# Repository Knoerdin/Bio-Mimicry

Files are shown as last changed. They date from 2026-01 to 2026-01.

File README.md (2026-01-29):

# Bio-Mimicry

## Code:
This project does not make use of any code, as the project is entirely analogue. However, there is a piece of simulation code for determining the deflection of different materials. Below is an explanation of how to use this code:
### Step 1:
To run the code, you'll need to install all dependencies. Do this by installing the requirements.txt file with this command:
```
pip install -r requirements.txt
```
### Step 2:
Now that you can run the code (assuming Python is installed...), go to the directory with the deflection.py in it and run the following command:
```
python3 deflection.py
```
This should start prompting values for these variables:
-   Material **name**
-   Beam **length** in meters
-   Beam **diameter** in centimeters
-   Beam **thickness** in millimeters
-   Material **modulus** of elasticity in pascals
-   Material **density** in kg/m³

After giving these variables a value, the program will ask you if you'd like to enter another entry. **Saying yes** will result in the same six questions and another entry in the data file. **Saying no** will plot all entries in the data file as a bar plot.\
When you are done with the simulation or need to exit, the data of the materials will be saved in deflection_results.txt for ease of use the next time the simulation is run.
## STL Files

This folder contains all 3D-printable parts used in the final prototype of the biomimetic bouldering hold gripper. The system consists of a pole-mounted tool head with a granular-jamming vacuum gripper, integrated drilling capability, onboard vacuum pump, and battery power supply.

### `accu_holder_los_helft.stl`
Single half of the slide-in battery holder that secures the battery pack and prevents connector movement during use.

### `conncection_drill_and_pole.stl`
Connector part that mechanically couples the drill and gripper head assembly to the aluminium pole.

### `filling_rig.stl`
Assembly aid used to hold the silicone membrane and clamping parts upright while filling the gripper with granular material.

### `handvat_half.stl`
One half of the handle shell that clamps around the pole and houses wiring, switches, and the drill trigger mechanism. To get the other half, just mirror this STL file before printing.

### `hinge_drill_connection.stl`
Tool-head-side hinge component that connects the gripper/drill assembly to the hinge mechanism.

### `hinge_pole_connection.stl`
Pole-side hinge component that mounts to the aluminium pole and the other hinge component

### `pump_holder+accu_helf_connected.stl`
Combined mount for the vacuum pump and battery interface that attaches to the pole and acts as a counterweight.

### `silicone_attachement_rings.stl`
Clamping rings used to secure the silicone membrane and create an airtight seal for the vacuum gripper.

### `silicone_cap_vacuum_attachment.stl`
Top cap of the gripper that connects the silicone membrane to the vacuum tubing. There is also a cutout for a ring filter.

### `silicone_mould_final_design.stl`
Mould used for casting the final silicone gripper membrane geometry.

## Miscellaneous:
Under the MISC folder, you'll find the poster used in the poster presentation given in Delft.
You'll also find the drawn electrical circuit connecting the drill and vacuum pump to the battery.

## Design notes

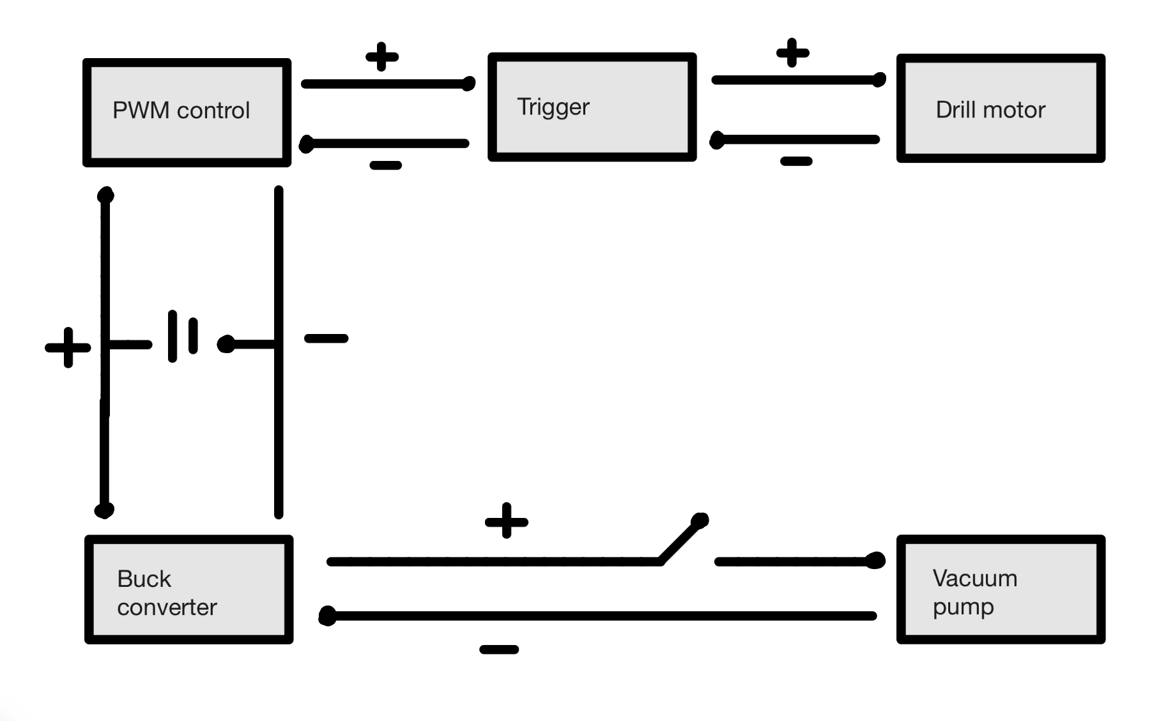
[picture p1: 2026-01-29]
MISC/electrical_circuit.jpg

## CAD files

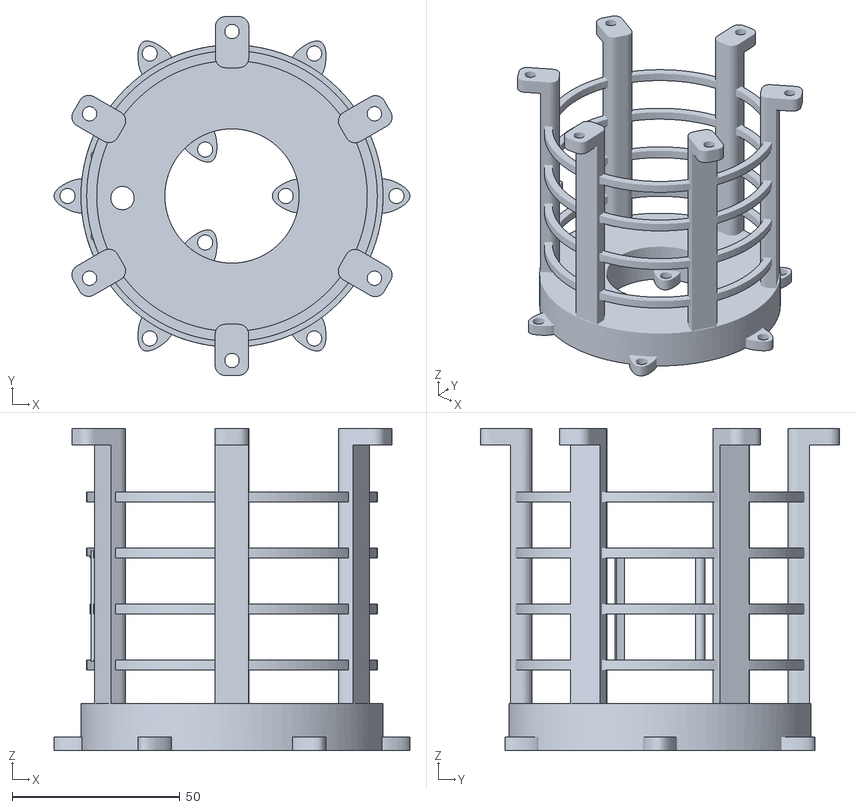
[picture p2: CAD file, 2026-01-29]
STL/silicone_cap_vacuum_attachment.stl
106.0 x 106.9 x 96.0

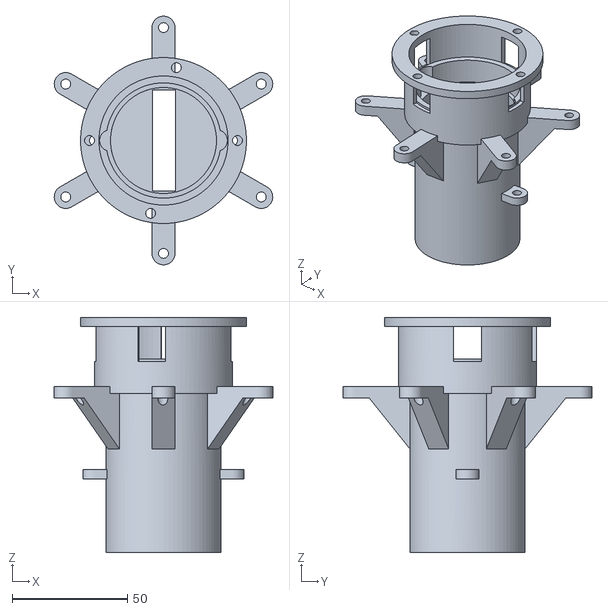
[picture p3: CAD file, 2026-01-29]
STL/conncection_drill_and_pole.stl
94.9 x 108.0 x 102.0

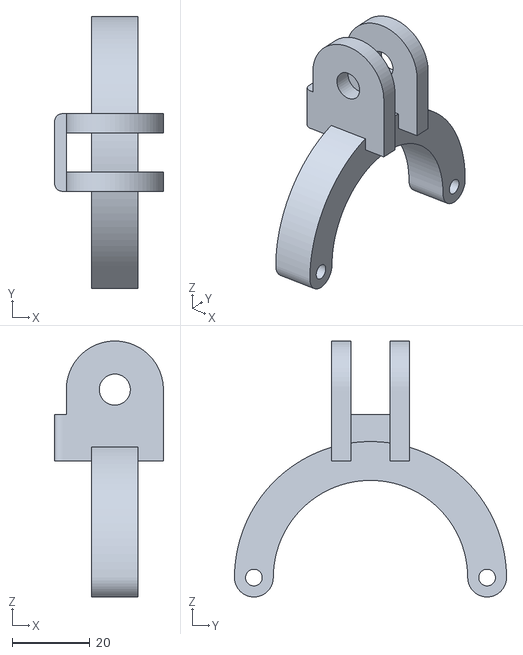
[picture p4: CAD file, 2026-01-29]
STL/hinge_drill_connection.stl
28.0 x 70.0 x 65.9

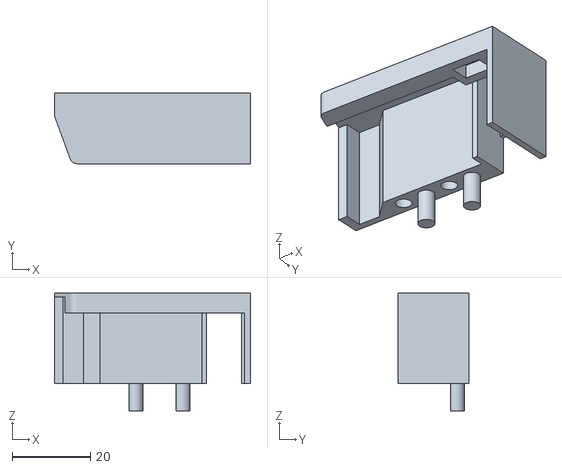
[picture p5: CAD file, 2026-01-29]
STL/accu_holder_los_helft.stl
50.0 x 18.0 x 30.0

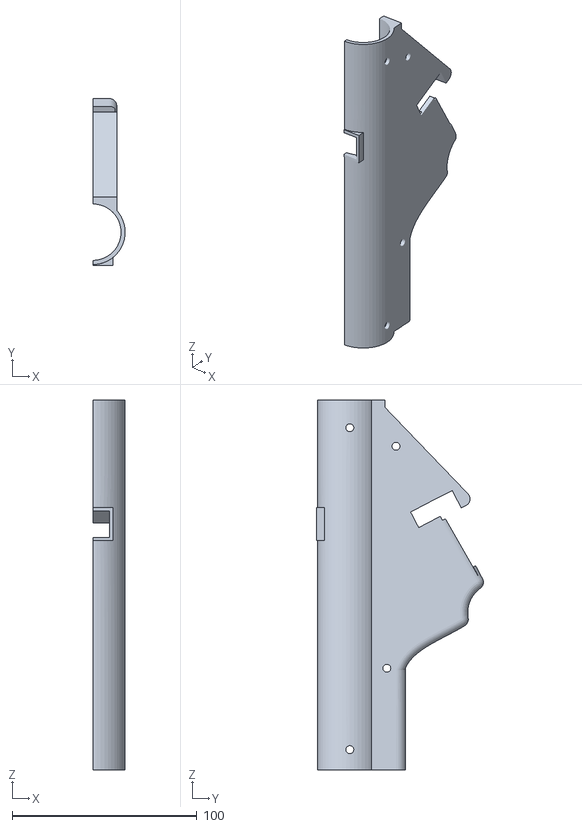
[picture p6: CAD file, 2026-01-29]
STL/handvat_half.stl
17.5 x 90.2 x 200.0

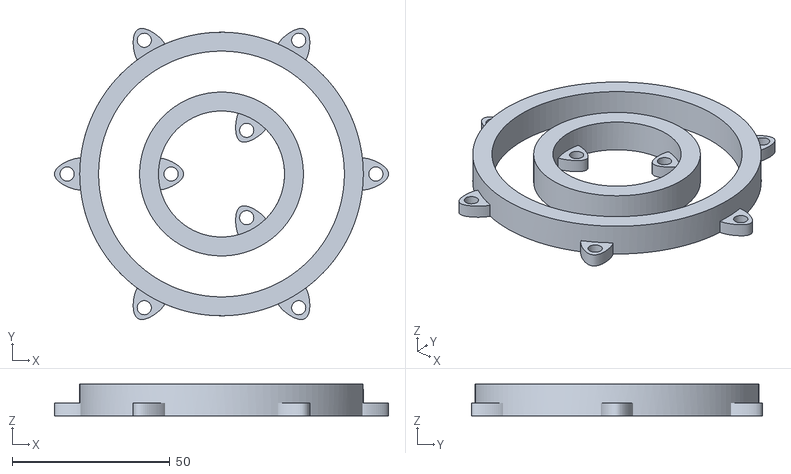
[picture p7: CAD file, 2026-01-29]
STL/silicone_attechement_rings.stl
106.0 x 92.4 x 10.0

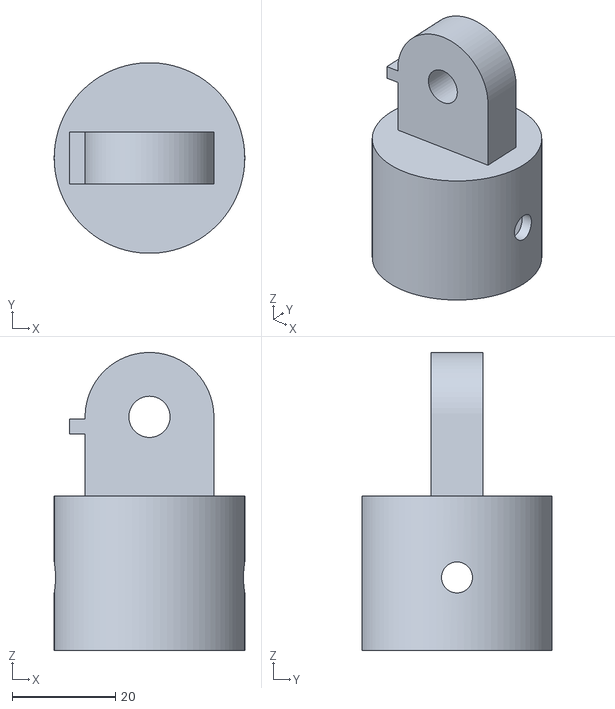
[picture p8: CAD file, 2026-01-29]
STL/hinge_pole_connection.stl
37.0 x 37.0 x 57.9

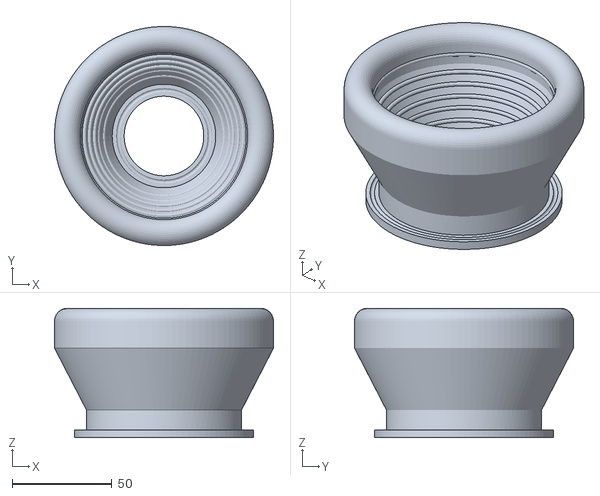
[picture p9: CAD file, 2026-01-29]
STL/silicone_mould_final_design.stl
110.0 x 110.0 x 65.0

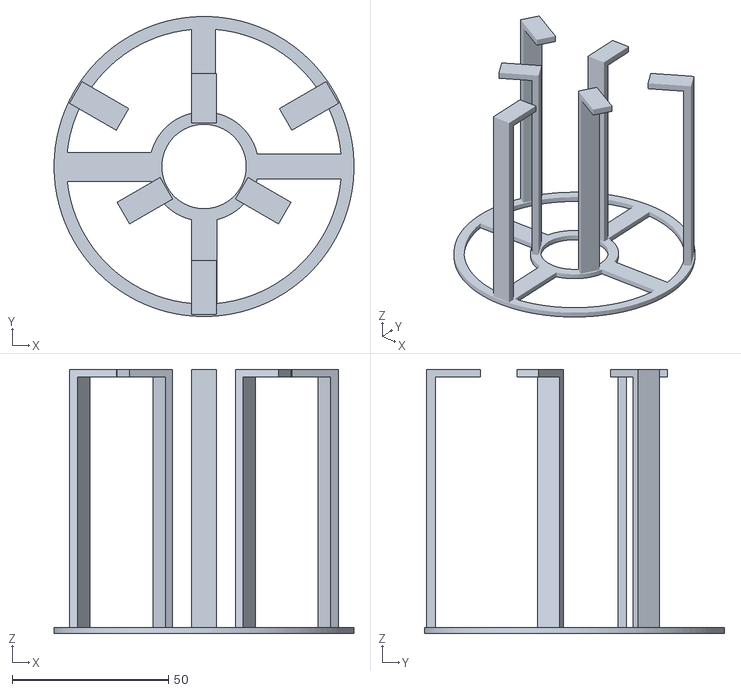
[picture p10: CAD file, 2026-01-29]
STL/filling_rig.stl
96.0 x 96.0 x 84.5

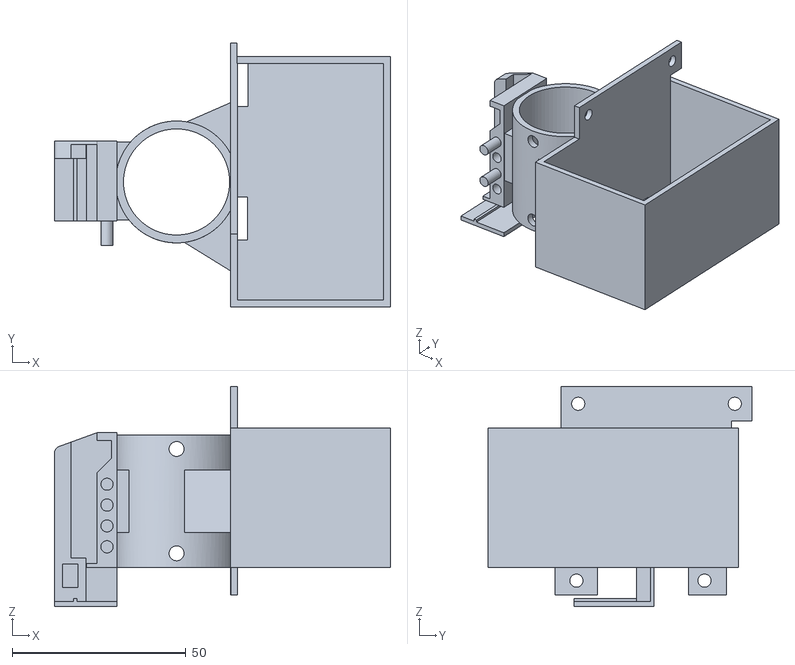
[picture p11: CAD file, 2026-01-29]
STL/pump_holder+accu_helf_connected.stl
96.6 x 76.0 x 63.3

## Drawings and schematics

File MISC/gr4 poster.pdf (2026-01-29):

1) Problem & Context | 2) First concepts

# Plan A

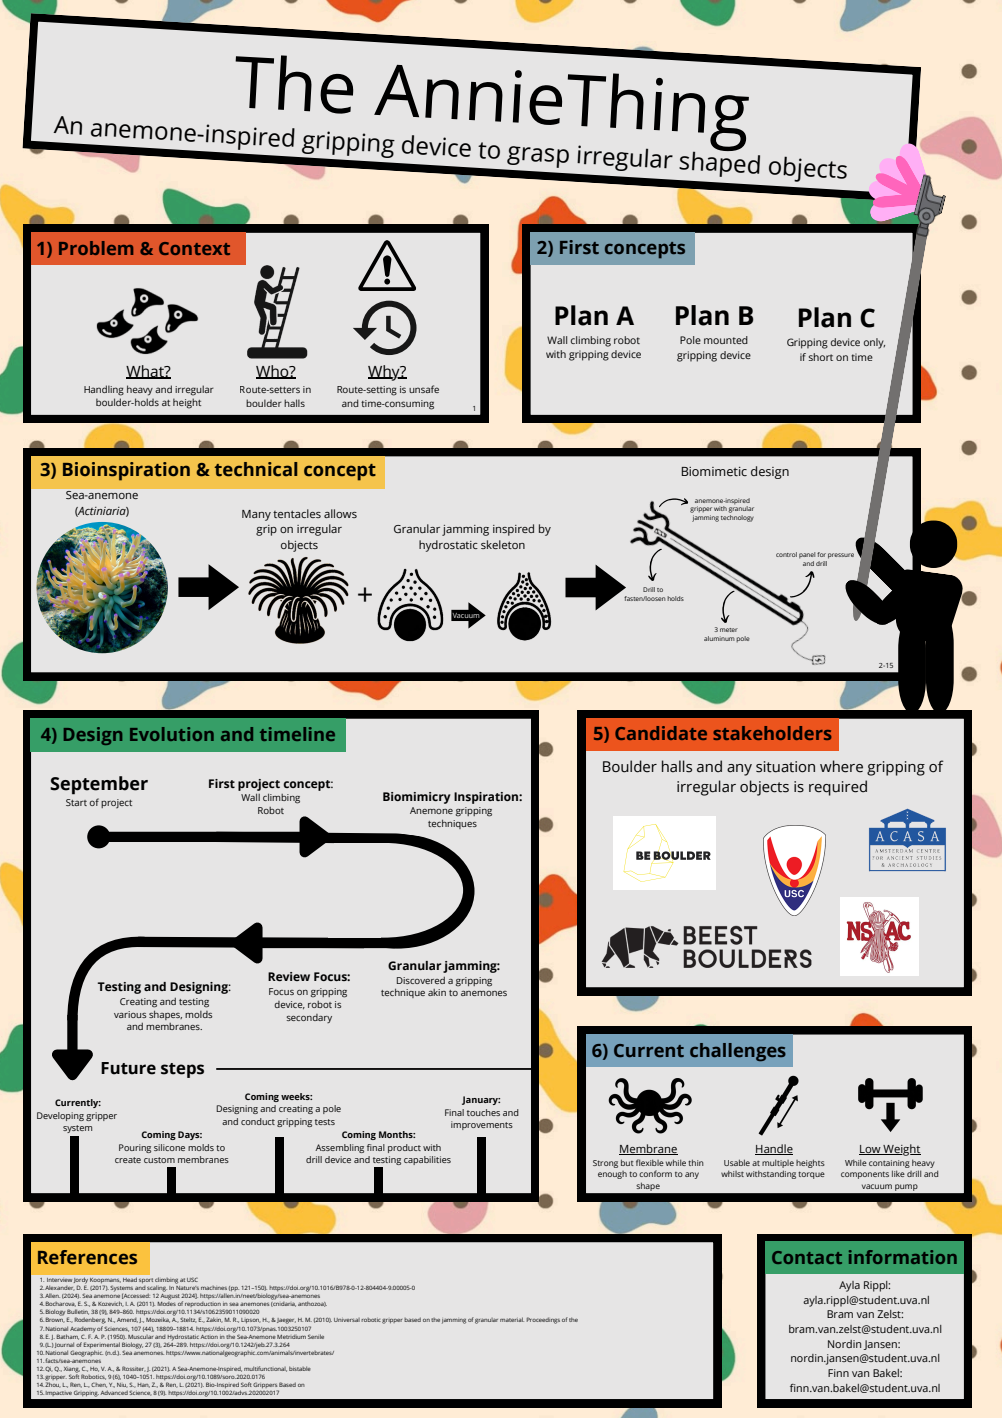
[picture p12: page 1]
Biomimetic design; and drill; 3 meter aluminum pole; Vacuum; The AnnieThing; References; Contact information; 6) Current challenges; 4) Design Evolution and timeline; 5) Candidate stakeholders; What?; Who?; Why?; Sea-anemone (Actiniaria); September; Biomimicry Inspiration: Anemone gripping techniques; Plan B; Pole mounted gripping device; Plan C; shape; Currently: Developing gripper system

An anemone-inspired gripping device to grasp irregular shaped objects

Wall climbing robot
with gripping device

Gripping device only,
if short on time

Handling heavy and irregular
boulder-holds at height

Route-setters in
boulder halls

Route-setting is unsafe
and time-consuming

3) Bioinspiration & technical concept

anemone-inspired
gripper with granular
jamming technology

Many tentacles allows
grip on irregular
objects

Granular jamming inspired by
hydrostatic skeleton

control panel for pressure

Drill to
fasten/loosen holds

Boulder halls and any situation where gripping of

First project concept:
Wall climbing
Robot

irregular objects is required

Start of project

Granular jamming:
Discovered a gripping
technique akin to anemones

Review Focus:
Focus on gripping
device, robot is
secondary

Testing and Designing:
Creating and testing
various shapes, molds
and membranes.
Future steps

Coming weeks:
Designing and creating a pole
and conduct gripping tests

January:
Final touches and
improvements

Coming Days:
Pouring silicone molds to
create custom membranes

Coming Months:
Assembling final product with
drill device and testing capabilities

Membrane
Strong but flexible while thin
enough to conform to any

Handle
Usable at multiple heights
whilst withstanding torque

Low Weight
While containing heavy
components like drill and
vacuum pump

1. Interview Jordy Koopmans, Head sport climbing at USC
2.Alexander, D. E. (2017). Systems and scaling. In Nature’s machines (pp. 121–150). https://doi.org/10.1016/B978-0-12-804404-9.00005-0
3.Allen. (2024). Sea anemone [Accessed: 12 August 2024]. https://allen.in/neet/biology/sea-anemones
4.Bocharova, E. S., & Kozevich, I. A. (2011). Modes of reproduction in sea anemones (cnidaria, anthozoa).
5.Biology Bulletin, 38 (9), 849–860. https://doi.org/10.1134/s1062359011090020
6.Brown, E., Rodenberg, N., Amend, J., Mozeika, A., Steltz, E., Zakin, M. R., Lipson, H., & Jaeger, H. M. (2010). Universal robotic gripper based on the jamming of granular material. Proceedings of the
7.National Academy of Sciences, 107 (44), 18809–18814. https://doi.org/10.1073/pnas.1003250107
8.E. J. Batham, C. F. A. P. (1950). Muscular and Hydrostatic Action in the Sea-Anemone Metridium Senile
9.(L.) Journal of Experimental Biology, 27 (3), 264–289. https://doi.org/10.1242/jeb.27.3.264
10.National Geographic. (n.d.). Sea anemones. https://www.nationalgeographic.com/animals/invertebrates/
11.facts/sea-anemones
12.Qi, Q., Xiang, C., Ho, V. A., & Rossiter, J. (2021). A Sea-Anemone-Inspired, multifunctional, bistable
13.gripper. Soft Robotics, 9 (6), 1040–1051. https://doi.org/10.1089/soro.2020.0176
14.Zhou, L., Ren, L., Chen, Y., Niu, S., Han, Z., & Ren, L. (2021). Bio-Inspired Soft Grippers Based on
15.Impactive Gripping. Advanced Science, 8 (9). https://doi.org/10.1002/advs.202002017

Ayla Rippl:
ayla.rippl@student.uva.nl
Bram van Zelst:
bram.van.zelst@student.uva.nl
Nordin Jansen:
nordin.jansen@student.uva.nl
Finn van Bakel:
finn.van.bakel@student.uva.nl

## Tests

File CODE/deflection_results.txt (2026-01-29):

{'deflection': 0.11551195771480324, 'material': 'Aluminium', 'length': 2.0, 'weight': 0.9500176184455532, 'diameter': 0.03, 'thickness': 0.002, 'elasticity': 70000000000.0}
{'deflection': 0.04555827149459738, 'material': 'Steel', 'length': 2.0, 'weight': 2.7620882610361455, 'diameter': 0.03, 'thickness': 0.002, 'elasticity': 200000000000.0}
{'deflection': 0.02622243480350485, 'material': 'Carbon-Fiber', 'length': 2.0, 'weight': 0.5629734035232907, 'diameter': 0.03, 'thickness': 0.002, 'elasticity': 300000000000.0}
{'deflection': 0.008660052106993912, 'material': 'Aluminium', 'length': 2.0, 'weight': 3.800070473782213, 'diameter': 0.06, 'thickness': 0.004, 'elasticity': 70000000000.0}
{'deflection': 0.00431328981105193, 'material': 'Steel', 'length': 2.0, 'weight': 11.048353044144582, 'diameter': 0.06, 'thickness': 0.004, 'elasticity': 200000000000.0}
{'deflection': 0.0018380899924779364, 'material': 'Carbon-Fiber', 'length': 2.0, 'weight': 2.251893614093163, 'diameter': 0.06, 'thickness': 0.004, 'elasticity': 300000000000.0}

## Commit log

2026-01-29 Added folderstructure and stl files
    [accu_holder_los_helft.stl, conncection_drill_and_pole.stl, filling_rig.stl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]
2026-01-29 Updated readme for stl files and misc
